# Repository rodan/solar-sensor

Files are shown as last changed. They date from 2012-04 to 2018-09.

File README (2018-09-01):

  Solar sensor device that implements the following:

   - read temperature, humidity, pressure and geiger counter sensors
   - read thermocouple temperature
   - read and set alarms in the real time clock
   - log sensor data on a microSD card
   - control room heating or cooling via RF power switches
   - use a communication protocol to send data to a PC

  there are 4 components in this repository:
  firmware_arduino  - contains the Arduino source code (avr version)
  firmware_avr      - stand-alone source code (avr version)
  hardware_avr      - open source hardware for the main board (avr version)
  server            - server-side implementation of the comm protocol

  pictures of rev02 and rev03 are available at 
            https://picasaweb.google.com/petre.rodan/SolarSensor

  Library dependencies for firmware_arduino software:

  ds3231      https://github.com/rodan/ds3231
  max6675     https://github.com/rodan/max6675
  bmp085      https://github.com/rodan/bmp085
  sht15       http://www.arduino.cc/playground/Code/Sensirion
  IRremote    https://github.com/shirriff/Arduino-IRremote
  SDfatlib    http://code.google.com/p/sdfatlib/

  dependencies for the server-side software:

  linux with working ftdi kernel driver
  sqlite      http://www.sqlite.org/
  gnuplot     http://www.gnuplot.info/

  Hardware needed:

  SHT15 Humidity and Temperature Sensor  - sparkfun sku: SEN-08257
  Grove - Geiger Counter - seeed studio sku: SEN63024P
  3W Solar Panel  - seeed studio sku: POW92136O
  Lithium Ion polymer Battery - 2Ah 3.7V  - seeed studio sku: POW103C1P
  XBee 2mW Chip Antenna - Series 2 ZigBee (2 pcs)  - sparkfun sku: WRL-10415
  XBee Explorer USB  - sparkfun sku: WRL-08687
  main board that includes the LiPo charger, DS3231 to wake up the system, 
    5v boost, one logic level converter, 3.3v stabilized sources, atmega328p uC, 
    uSD card socket, xbee socket, digital cold junction compensated K-type 
    thermocouple IC and mosfets to power off unused modules.

  How does it work

    Power: the main power is from a 2Ah LiPo cell that is charged from the solar panel. a stabilization circuit and a boost give out 3.3V and 5V respectively. a small coin cell battery keeps the DS3231 RTC chip working at all times. the RTC's alarm function is waking up the microcontroller once every 30 minutes.

    Sensors: some are internal and some kept outside. The outside temperature and humidity are measured by a SHT15 chip. the Geiger-Muller tube is also kept outside. the internal temperature is read from the RTC chip, or via a K-type thermocouple.

    Sensor data: is saved to a uSD card and if the receiving PC is up and if the wireless signal haven't got too much interference than a protocol is used to send new data to the PC. it ends up here: http://www.simplex.ro/ro/statie_meteo.html

    Commands: are being given either via the wireless serial interface or via a universal remote control that can speak RC5 (most remotes can).

  Author:          Petre Rodan <2b4eda@subdimension.ro>
  Available from:  https://github.com/rodan/solar-sensor
  License:         GNU GPLv3

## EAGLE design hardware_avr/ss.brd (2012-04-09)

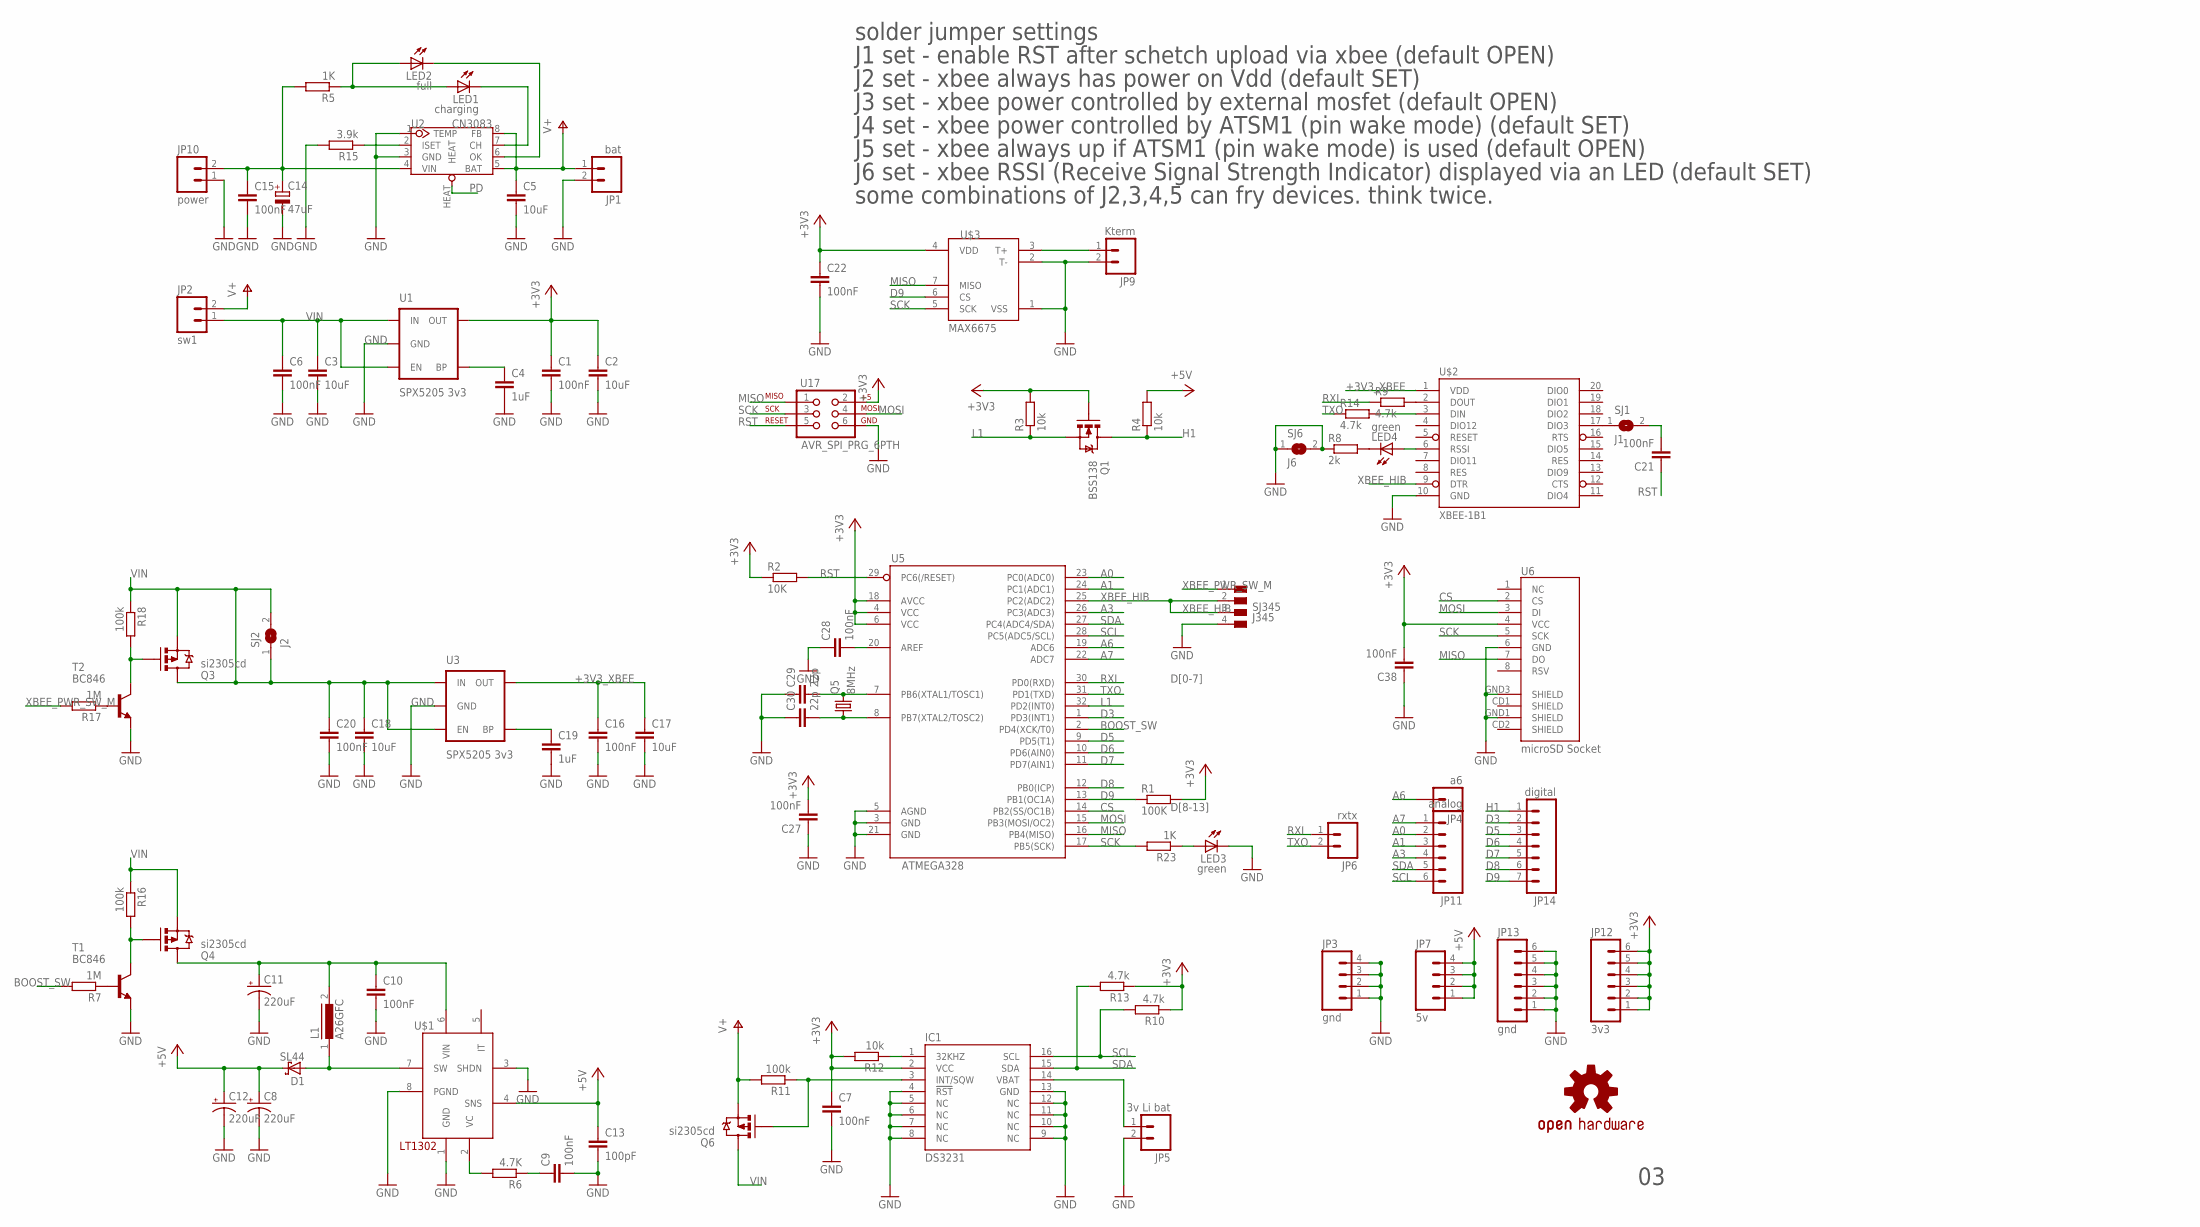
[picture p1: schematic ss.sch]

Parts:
C1, C6, C7, C9, C10, C15, C16, C20, C21, C22, C27, C28, C38: 100nF; C0805
C2, C3, C5, C17, C18: 10uF; C1206
C4, C19: 1uF; C0805
C8, C11, C12: 220uF; PANASONIC_D
C13: 100pF; C0805
C14: 47uF; CT7343
C29, C30: 22p; C0805
D1: SL44; SMC
IC1: DS3231; SO-16
JP1: bat; 1X02
JP2: sw1; 1X02
JP3: gnd; 1X04
JP4: a6; 1X01
JP5: 3v Li bat; 1X02
JP6: rxtx; 1X02
JP7: 5v; 1X04
JP9: Kterm; 1X02
JP10: power; 1X02
JP11: analog; 1X06
JP12: 3v3; 1X06
JP13: gnd; 1X06
JP14: digital; 1X07
L1: A26GFC
LED1: charging; CHIP-LED0805
LED2: full; CHIP-LED0805
LED3, LED4: green; CHIP-LED0805
Q1: BSS138; SOT23-3
Q3, Q4, Q6: si2305cd; SOT23-3_POWER
Q5: 8MHz; CRYSTAL_5X3.2
R1: 100K; R0805W
R2: 10K; R0805W
R3, R4, R12: 10k; R0805W
R5, R23: 1K; R0805W
R6: 4.7K; R0805W
R7, R17: 1M; R0805W
R8: 2k; R0805W
R9, R10, R13, R14: 4.7k; R0805W
R11, R16, R18: 100k; R0805W
R15: 3.9k; R0805W
SJ1: J1; SJ
SJ2: J2; SJ
SJ6: J6; SJ
SJ345: J345; SJ_4P
T1, T2: BC846; SOT23
U1, U3: SPX5205 3v3; SOT23-5
U2: CN3083; SOP8-W/-HEAT
U5: ATMEGA328; TQFP32-08
U6: microSD Socket; MICRO-SD-SOCKET-PP
U17: AVR_SPI_PRG_6PTH; 2X3
U$1: LT1302SOIC8; SO08
U$2: XBEE-1B1; XBEE-1
U$3: MAX6675; SO08-MAX6675
U$7: OSHW-LOGOM; OSHW-LOGO-M

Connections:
+3V3: C1.1, C2.1, C7.1, C22.1, C27.2, C38.2, IC1.2 (VCC), JP12.1, JP12.2, JP12.3, JP12.4, JP12.5, JP12.6, Q1.1 (G), R1.2, R2.1, R3.2, R10.1, R12.2, R13.1, U1.5 (OUT), U5.4 (VCC), U5.6 (VCC), U5.18 (AVCC), U6.4 (VCC), U17.2, U$3.4 (VDD)
+3V3_XBEE: C16.1, C17.1, U3.5 (OUT), U$2.1 (VDD)
+5V: C8.+, C12.+, C13.1, D1.C, JP7.1, JP7.2, JP7.3, JP7.4, R4.2, U$1.4 (SNS)
A0: JP11.2, U5.23 (PC0(ADC0))
A1: JP11.3, U5.24 (PC1(ADC1))
A3: JP11.4, U5.26 (PC3(ADC3))
A6: JP4.1, U5.19 (ADC6)
A7: JP11.1, U5.22 (ADC7)
BOOST_IN: C10.1, C11.+, L1.2, Q4.3 (D), U$1.6 (VIN)
BOOST_SW: R7.2, U5.2 (PD4(XCK/T0))
CS: U5.14 (PB2(SS/OC1B)), U6.2 (CS)
D3: JP14.2, U5.1 (PD3(INT1))
D5: JP14.3, U5.9 (PD5(T1))
D6: JP14.4, U5.10 (PD6(AIN0))
D7: JP14.5, U5.11 (PD7(AIN1))
D8: JP14.6, U5.12 (PB0(ICP))
D9: JP14.7, R1.1, U5.13 (PB1(OC1A)), U$3.6 (CS)
GND: C1.2, C2.2, C3.2, C4.2, C5.2, C6.2, C7.2, C8.-, C9.2, C10.2, C11.-, C12.-, C13.2, C14.-, C15.2, C16.2, C17.2, C18.2, C19.2, C20.2, C22.2, C27.1, C28.1, C29.1, C30.1, C38.1, IC1.4 (!RST), IC1.5 (NC), IC1.6 (NC), IC1.7 (NC), IC1.8 (NC), IC1.9 (NC), IC1.10 (NC), IC1.11 (NC), IC1.12 (NC), IC1.13 (GND), JP1.2, JP3.1, JP3.2, JP3.3, JP3.4, JP5.2, JP9.2, JP10.1, JP13.1, JP13.2, JP13.3, JP13.4, JP13.5, JP13.6, LED3.C, R8.1, R15.2, SJ6.1, SJ6.2, SJ345.4, T1.2 (E), T2.2 (E), U1.2 (GND), U2.1 (TEMP), U2.3 (GND), U3.2 (GND), U5.3 (GND), U5.5 (AGND), U5.21 (GND), U6.6 (GND), U6.GND1 (SHIELD), U6.GND3 (SHIELD), U17.6, U$1.1 (GND), U$1.3 (SHDN), U$1.8 (PGND), U$2.10 (GND), U$3.1 (VSS), U$3.2 (T-)
H1: JP14.1, Q1.3 (D), R4.1
L1: Q1.2 (S), R3.1, U5.32 (PD2(INT0))
MISO: U5.16 (PB4(MISO)), U6.7 (DO), U17.1, U$3.7 (MISO)
MOSI: U5.15 (PB3(MOSI/OC2)), U6.3 (DI), U17.4
unnamed: IC1.3 (INT/SQW), Q6.1 (G), R11.1
unnamed: C4.1, U1.4 (BP)
unnamed: D1.A, L1.1, U$1.7 (SW)
unnamed: SJ1.1, U$2.17 (DIO3)
unnamed: C19.1, U3.4 (BP)
unnamed: LED4.C, R8.2
unnamed: LED4.A, U$2.6 (RSSI)
unnamed: IC1.1 (32KHZ), R12.1
unnamed: R15.1, U2.2 (ISET)
unnamed: IC1.14 (VBAT), JP5.1
unnamed: R6.2, U$1.2 (VC)
unnamed: C14.+, C15.1, JP10.2, R5.2, U2.4 (VIN)
unnamed: C9.1, R6.1
unnamed: LED1.A, LED2.A, R5.1
unnamed: LED1.C, U2.7 (CH)
unnamed: LED2.C, U2.6 (OK)
unnamed: C21.2, SJ1.2
unnamed: R17.1, T2.1 (B)
unnamed: C30.2, Q5.P$1 (1), U5.8 (PB7(XTAL2/TOSC2))
unnamed: Q3.1 (G), R18.2, T2.3 (C)
unnamed: C29.2, Q5.P$2 (2), U5.7 (PB6(XTAL1/TOSC1))
unnamed: C28.2, U5.20 (AREF)
unnamed: R9.2, U$2.2 (DOUT)
unnamed: R14.2, U$2.3 (DIN)
unnamed: R7.1, T1.1 (B)
unnamed: Q4.1 (G), R16.2, T1.3 (C)
unnamed: LED3.A, R23.1
PD: U2.HEAT
RST: C21.1, R2.2, U5.29 (PC6(/RESET)), U17.5
RXI: JP6.1, R9.1, U5.30 (PD0(RXD))
SCK: R23.2, U5.17 (PB5(SCK)), U6.5 (SCK), U17.3, U$3.5 (SCK)
SCL: IC1.16 (SCL), JP11.6, R10.2, U5.28 (PC5(ADC5/SCL))
SDA: IC1.15 (SDA), JP11.5, R13.2, U5.27 (PC4(ADC4/SDA))
T+: JP9.1, U$3.3 (T+)
TXO: JP6.2, R14.1, U5.31 (PD1(TXD))
V+: C5.1, JP1.1, JP2.2, Q6.2 (S), R11.2, U2.5 (BAT), U2.8 (FB)
VIN: C3.1, C6.1, C18.1, C20.1, JP2.1, Q3.2 (S), Q3.3 (D), Q4.2 (S), Q6.3 (D), R16.1, R18.1, SJ2.1, SJ2.2, U1.1 (IN), U1.3 (EN), U3.1 (IN), U3.3 (EN)
XBEE_HIB: SJ345.2, SJ345.3, U5.25 (PC2(ADC2)), U$2.9 (DTR)
XBEE_PWR_SW_M: R17.2, SJ345.1

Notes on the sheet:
D[0-7]
D[8-13]
J1 set - enable RST after schetch upload via xbee (default OPEN)
J2 set - xbee always has power on Vdd (default SET)
solder jumper settings
J3 set - xbee power controlled by external mosfet (default OPEN)
J4 set - xbee power controlled by ATSM1 (pin wake mode) (default SET)
J5 set - xbee always up if ATSM1 (pin wake mode) is used (default OPEN)
J6 set - xbee RSSI (Receive Signal Strength Indicator) displayed via an LED (default SET)
some combinations of J2,3,4,5 can fry devices. think twice.

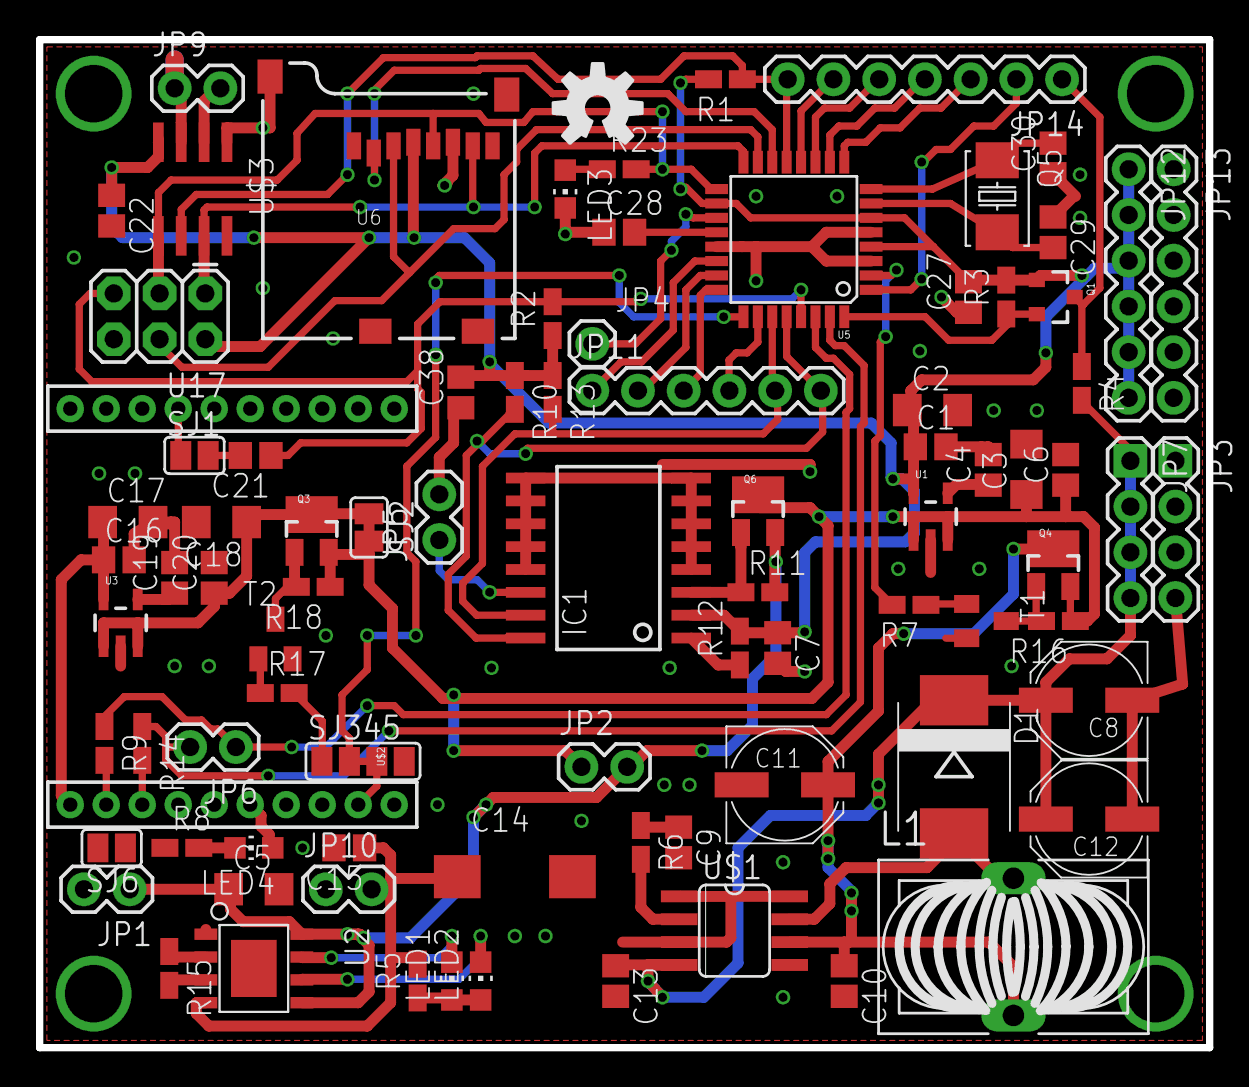
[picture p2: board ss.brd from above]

Board: 2 copper layers, 65.0 x 56.0 mm, 87 parts (0 on the bottom side), 60 nets.

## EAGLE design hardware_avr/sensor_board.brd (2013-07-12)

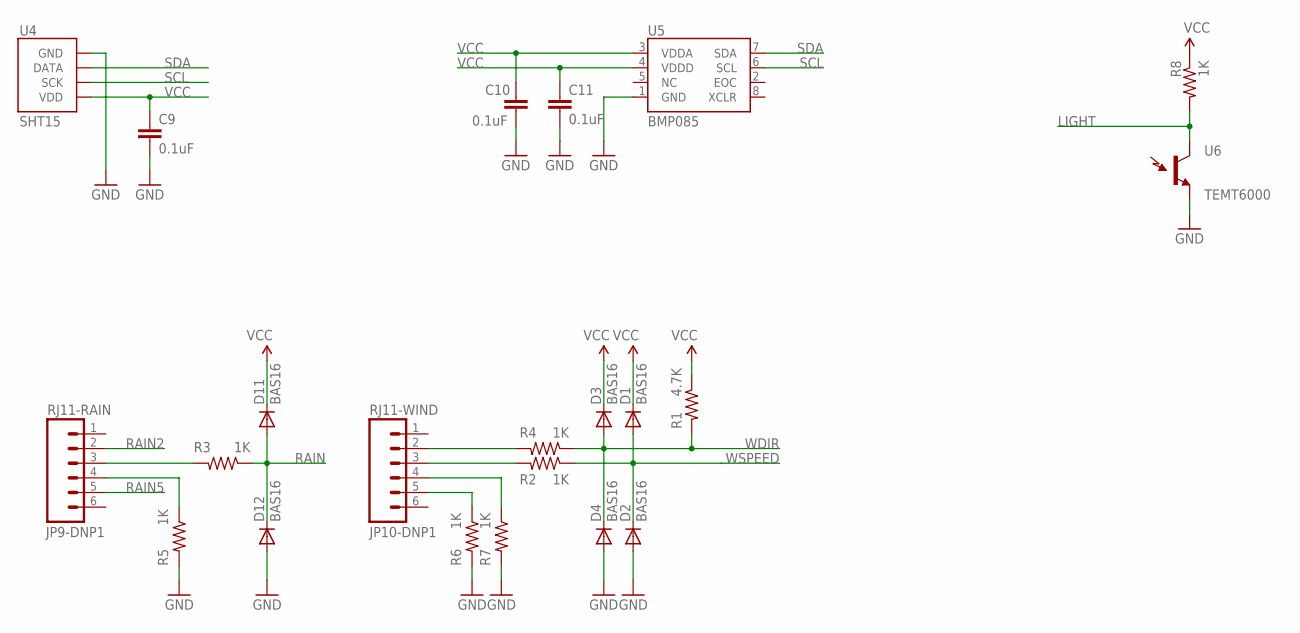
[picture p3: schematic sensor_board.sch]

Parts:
C9, C10, C11: 0.1uF; 0402-CAP
D1, D2, D3, D4, D11, D12: BAS16; SOD-323
JP9-DNP1: RJ11-RAIN; RJ11-6
JP10-DNP1: RJ11-WIND; RJ11-6
R1: 4.7K; 0402-RES
R2, R3, R4, R5, R6, R7, R8: 1K; 0402-RES
U4: SHT15; SHT1X
U5: BMP085
U6: TEMT6000; TEMT6000-SEN

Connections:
GND: C9.2, C10.1, C11.2, D2.2 (A), D4.2 (A), D12.2 (A), R5.2, R6.2, R7.2, U4.1 (GND), U5.1 (GND), U6.EMITTER (E1)
LIGHT: R8.2, U6.COLLECTOR (C1)
unnamed: JP10-DNP1.2, R4.2
unnamed: JP10-DNP1.3, R2.2
unnamed: JP9-DNP1.3, R3.2
unnamed: JP9-DNP1.4, R5.1
unnamed: JP10-DNP1.5, R6.1
unnamed: JP10-DNP1.4, R7.1
RAIN: D11.2 (A), D12.1 (C), R3.1
RAIN2: JP9-DNP1.2
RAIN5: JP9-DNP1.5
SCL: U4.3 (SCK), U5.6 (SCL)
SDA: U4.2 (DATA), U5.7 (SDA)
VCC: C9.1, C10.2, C11.1, D1.1 (C), D3.1 (C), D11.1 (C), R1.1, R8.1, U4.4 (VDD), U5.3 (VDDA), U5.4 (VDDD)
WDIR: D3.2 (A), D4.1 (C), R1.2, R4.1
WSPEED: D1.2 (A), D2.1 (C), R2.1

Board: 2 copper layers, 22 parts (0 on the bottom side), 14 nets, no tracks yet.

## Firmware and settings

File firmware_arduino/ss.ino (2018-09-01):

/*

  Solar sensor program that implements the following:

   - read temperature, humidity and geiger counter sensors
   - read and set alarms in the real time clock
   - log sensor data on an microSD card
   - use a communication protocol to send data to a server
   - control room heating or cooling via RF power switches (based on internal temperatures)

  see the README file for more info.

  Author:          Petre Rodan <2b4eda@subdimension.ro>
  Revision:        03
  Available from:  https://github.com/rodan/solar-sensor
  License:         GNU GPLv3

  GNU GPLv3 license:
  
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
*/

#include "config.h"

#ifdef IR_REMOTE
#include <IRremote.h>
#include <IRremoteInt.h>
#endif

#ifdef SHT15
#include <Sensirion.h>
#endif

#ifdef MAX6675
#include <max6675.h>
#endif

#ifdef BMP085
#include <bmp085.h>
#endif

#ifdef INTERTECHNO
#include <intertechno.h>
#endif

#include <Wire.h>
#include <ds3231.h>
#include <SPI.h>

#ifdef SDFAT
#include <SdFat.h>
#include <SdFatUtil.h>
#endif

#include "ss.h"

#define SENSOR_ID 1

// XBEE_ACTIVE_LOW must be 1 with the following jumper settings:
//   J2 set, J3 open, J4 set, J5 open 
//            (xbee always receives power, hibernating if ATSM1 set - this is the default state)
//   J2 set, J3 open, J4 open, J5 set 
//            (xbee always receives power, always active if ATSM1 set) 
//
// XBEE_ACTIVE_LOW must be 0 with the following jumper settings:
//   J2 open, J3 set, J4 open, J5 set
//            (xbee receives power only when pin_xbee_ctrl is HIGH)
//
#define XBEE_ACTIVE_LOW "1"

// arduino digital pins
#define pin_counter 2
#define pin_ir 3
#define pin_boost_sw 4
#define pin_rf 5
#define pin_SHT_SCK 8
#define pin_cs_kterm 9

// analog pins
#define pin_xbee_ctrl A2
#define pin_light A3
#define pin_SHT_DATA A4
//SDA   A4
//SCL   A5

// OP_AUTOMATIC - when the device is woken up by the RTC
// OP_MANUAL - when the device is woken up by a human
#define OP_MANUAL 0
#define OP_AUTOMATIC 1
unsigned char op_mode = OP_AUTOMATIC;

// how many minutes to sleep between automatic measurements
// must be an integer between 5 and 59

#ifdef DATALOGGER
unsigned char sleep_period = 1;
#else
unsigned char sleep_period = 30;
#endif

unsigned long stage_prev = 0;
boolean stage_started[7] = { false, false, false, false, false, false, false };

byte stage_num = 0;

// refresh in OP_MANUAL mode
unsigned long refresh_prev = 0;

// not much space for misc buffers
#define BUFF_MAX 64

float ext_temp = 0.0;
float ext_hum = 0.0;
float ext_dew = 0.0;
uint32_t ext_pressure = 0;
uint8_t ext_light = 0;

// Ktherm
float kth_temp = 0.0;

#ifdef BMP085
// bmp085 pressure sensor
struct bmp085 b;
#endif

#ifdef INTERTECHNO
// intertechno rf switch
struct it its;
#endif

// rtc
struct ts t;
float int_temp;

// serial console
char recv[BUFF_MAX];
uint8_t recv_size = 0;

unsigned long shtd_prev = 0;

#ifdef SDFAT
#define BUFF_LOG 64
// uSD
SdFat sd;
SdFile f;
#endif

#ifdef IR_REMOTE
// infrared remote
IRrecv irrecv(pin_ir);
unsigned long result_last = 4294967295UL;       // -1
unsigned int ir_delay = 300;    // delay between repeated button presses
unsigned long ir_delay_prev = 0;
#endif

// counter
boolean counter_state = HIGH;
boolean counter_state_last = HIGH;
volatile unsigned long counter_c = 0;   //counts
unsigned long counter_c_last = 0;       //counts at start of counter_interval
unsigned long counter_cpm;      //counts per interval
//unsigned long counter_interval = 60000;
unsigned long counter_prev = 0;

#define BUFF_OUT 80
char output[BUFF_OUT];

void setup()
{
    pinMode(pin_counter, INPUT);
    pinMode(pin_xbee_ctrl, OUTPUT);
    pinMode(pin_boost_sw, OUTPUT);

    xbee_off();
    Wire.begin();
    TWBR = 0xFF;                // slow down hardware i2c clock
    // since we use longer than recommended wires

    // verify if Alarm2 woked us up  ( status register XXXX XX1X )
    if ((DS3231_get_sreg() & 0x02) == 0) {
        // powered up by manual switch, not by alarm
        op_mode = OP_MANUAL;
        //stage4();
    }
        
    setup_a2();
    
    // this will pull up D9 - needed for later SPI
#ifdef MAX6675
    tk_init(pin_cs_kterm);
#else
    pinMode(pin_cs_kterm, OUTPUT);
    digitalWrite(pin_cs_kterm, HIGH);
#endif

#ifdef SDFAT
    if (!sd.init(SPI_HALF_SPEED))
        sd.initErrorHalt();
#endif

    DS3231_init(0x06);
    Serial.begin(9600);

#ifdef BMP085
    bmp085_init(&b);
#endif

#ifdef INTERTECHNO
    its.pin = pin_rf;
#if defined(F_CPU) && F_CPU == 8000000
    its.rf_cal_on = -7;
    its.rf_cal_off = -7;
#elif defined(F_CPU) && F_CPU == 16000000
    its.rf_cal_on = -1;
    its.rf_cal_off = -1;
#else
    // mkaaaaay
    its.rf_cal_on = -1;
    its.rf_cal_off = -1;
#endif
    pinMode(its.pin, OUTPUT);
    digitalWrite(its.pin, LOW);

#endif

#ifdef IR_REMOTE
    irrecv.enableIRIn();
#endif
    //Serial.print("ram ");
    //Serial.println(FreeRam());
    //Serial.println("?");
}

void loop()
{

    // initial wait, warmup, counter, hum, post wait, sleep
    //unsigned long stage_timing[7] = { 2000, 4000, 60000, 1000, 20000, 5000, (sleep_period * 60000) - 108000 };
#ifdef DATALOGGER
    unsigned long stage_timing[7] = { 2000, 4000, 1, 1000, 20000, 5000, (sleep_period * 60000) - 108000 };
#else
    unsigned long stage_timing[7] = { 2000, 4000, 60000, 1000, 20000, 60000, (sleep_period * 60000) - 108000 };
#endif

    unsigned long now = millis();

#ifdef IR_REMOTE
    ir_decode();
#endif

    console_decode();

    if (op_mode == OP_AUTOMATIC) {
        switch (stage_num) {
        case 0:
            if (!stage_started[1] && (now - stage_prev > stage_timing[0])) {
                stage_prev = now;
                stage_started[0] = false;
                stage_started[1] = true;
                stage1();
            }
            break;
        case 1:
            if (!stage_started[2] && (now - stage_prev > stage_timing[1])) {
                stage_prev = now;
                stage_started[1] = false;
                stage_started[2] = true;
                stage2();
            }
            break;
        case 2:
            read_counter();
            if (!stage_started[3] && (now - stage_prev > stage_timing[2])) {
                stage_prev = now;
                stage_started[2] = false;
                stage_started[3] = true;
                stage3();
            }
            break;
        case 3:
            if (!stage_started[4] && (now - stage_prev > stage_timing[3])) {
                stage_prev = now;
                stage_started[3] = false;
                stage_started[4] = true;
                stage4();
            }
            break;
        case 4:
            if (!stage_started[5] && (now - stage_prev > stage_timing[4])) {
                stage_prev = now;
                stage_started[4] = false;
                stage_started[5] = true;
                stage5();
            }
            break;
        case 5:
            if (!stage_started[6]
                && ((now - stage_prev > stage_timing[5])
                    || (now - shtd_prev > 20000))) {
                // if there is more than 20s of inactivity, shutdown
                stage_prev = now;
                stage_started[5] = false;
                stage_started[6] = true;
                stage6();
            }
        case 6:
            if (!stage_started[0] && (now - stage_prev > stage_timing[6])) {
                stage_prev = now;
                stage_started[6] = false;
                stage_started[0] = true;
                stage_num = 0;
            }
            break;

        }                       // switch
    } else {                    // manual operation

        read_counter();

        if ((now - counter_prev > 60000)) {
            counter_cpm = counter_c - counter_c_last;
            counter_c_last = counter_c;
            counter_prev = now;
        }
        // once a while (10s) refresh stuff
        if ((now - refresh_prev > 10000)) {
            refresh_prev = now;

            // if the RTC woke up the device in the meantime
            if ((DS3231_get_sreg() & 0x02) == 2) {
                // clear all alarms and thus disable RTC poweron
                DS3231_set_sreg(0x00);
                setup_a2();
            }
        }
    }

}

#ifdef DEBUG
void log_debug(const char *s)
{
    Serial.print("DBG ");
    Serial.print(millis());
    Serial.print(" ");
    Serial.println(s);
}
#endif

// IR
#ifdef IR_REMOTE
void ir_decode()
{
    decode_results results;
    unsigned long now = millis();

    //int ir_number = -1;

    if (irrecv.decode(&results)) {

        if (results.value >= 2048)
            results.value -= 2048;

        if (result_last == results.value && now - ir_delay_prev < ir_delay) {
            results.value = 11111;
        }

        switch (results.value) {
/*      // RC5 codes
        case 1: // 1
            ir_number = 1;
            break;
        case 2: // 2
            ir_number = 2;
            break;
        case 3: // 3
            ir_number = 3;
            break;
        case 4: // 4
            ir_number = 4;
            break;
        case 5: // 5
            ir_number = 5;
            break;
        case 6: // 6
            ir_number = 6;
            break;
        case 7: // 7
            ir_number = 7;
            break;
        case 8: // 8
            ir_number = 8;
            break;
        case 9: // 9
            ir_number = 9;
            break;
        case 0: // 0
            ir_number = 0;
            break;
        case 10: // 10
            ir_number = 10;
            break;
*/
        case 56:               // AV
            Serial.println("");
            Serial.print("EHLO s");
            Serial.println(SENSOR_ID);
            break;
/*
        case 36: // red
          break;
        case 35: // green
          break;
        case 14: // yellow
          break; */
        case 12:               // power
            op_mode = OP_MANUAL;
            if ((DS3231_get_sreg() & 0x02) == 2) {
                // clear all alarms and thus disable RTC poweron
                DS3231_set_sreg(0x00);
            }
            break;
/*        case 50: // zoom
            break;
        case 39: // sub
            break;
        case 44: // slow
            break;
        case 60: // repeat
            break;
        case 15: // disp
            break;
        case 38: // sleep
            break;
        case 32: // up
            break;
        case 33: // down
            break;
        case 16: // right
            break;
        case 17: // left
            break;
        case 59: // ok
            break;
        case 34: // back
            break;
        case 19: // exit
            break;
        case 18: // menu
            break;
        case 13: // mute
            break;
        case 16: // vol+
            break;
        case 17: // vol-
            break;
        case 28: // ch+
            rf_tx_cmd(its, 0xb6, INTERTECHNO_CMD_ON);
            break;
        case 29: // ch-
            rf_tx_cmd(its, 0xb6, INTERTECHNO_CMD_OFF);
            break;
*/
        case 36:               // record
            Serial.println("GET time");
            break;
        case 54:               // stop
            xbee_off();
            boost_off();
            break;
        case 14:               // play
            xbee_on();
            boost_on();
            break;
/*        case 31: // pause
            break;
*/
        case 35:               // rew
            stage4();
            break;
/*        case : // fwd
            break;
*/
        }                       // case

        if (results.value != 11111) {
            result_last = results.value;
            ir_delay_prev = now;
        }
        irrecv.resume();        // Receive the next keypress
    }

}
#endif

//   sensors

int measure_ext()
{

#ifdef SHT15
    uint16_t sht_raw;
    Sensirion sht = Sensirion(pin_SHT_DATA, pin_SHT_SCK);

    // disable hardware i2c
    TWCR &= ~(1 << 2);
    pinMode(pin_SHT_SCK, OUTPUT);

    sht.meas(TEMP, &sht_raw, BLOCK);
    ext_temp = sht.calcTemp(sht_raw);
    if (ext_temp == -40.1) {
        ext_temp = 0;
        return 1;
    }
    sht.meas(HUMI, &sht_raw, BLOCK);
    ext_hum = sht.calcHumi(sht_raw, ext_temp);
    ext_dew = sht.calcDewpoint(ext_hum, ext_temp);

    TWCR |= (1 << 2);           // enable hardware i2c
    //Wire.begin();
    //TWBR = 0xFF;
#else
    ext_hum = 0;
    ext_temp = 0;
    ext_dew = 0;
#endif

#ifdef BMP085
    b.oss = 3;
    bmp085_read_sensors(&b);
    ext_pressure = b.ppa;
#endif

    ext_light = analogRead(pin_light) / 4;

    return 0;
}

void measure_int()
{
    int_temp = DS3231_get_treg();
#ifdef MAX6675
    kth_temp = 0.25 * tk_get_raw(pin_cs_kterm);
#endif
}

void read_counter()
{
    counter_state = digitalRead(pin_counter);
    if (counter_state != counter_state_last) {
        if (counter_state == LOW) {
            counter_c++;
        }
        counter_state_last = counter_state;
    }
}

void stage1()
{
    stage_num = 1;

#ifdef DEBUG
    const char msg[] = "s1";
    log_debug(msg);
#endif

    boost_on();
}

void stage2()
{
    stage_num = 2;

#ifdef DEBUG
    const char msg[] = "s2";
    log_debug(msg);
#endif

    counter_c_last = counter_c;
}

void stage3()
{
    stage_num = 3;

#ifdef DEBUG
    const char msg[] = "s3";
    log_debug(msg);
#endif

//  counter_cpm = ( counter_c - counter_c_last ) * 60000.0 / counter_interval;
    counter_cpm = counter_c - counter_c_last;
    boost_off();
    xbee_on();
}

void stage4()
{
    char tmp1[7], tmp2[7], tmp3[7], tmp4[7], tmp5[9];
    stage_num = 4;

#ifdef DEBUG
    const char msg[] = "s4";
    log_debug(msg);
#endif

    measure_ext();
    measure_int();

    DS3231_get(&t);

    // floats cannot be used as %f in *printf()
    dtostrf(ext_temp, 2, 2, tmp1);
    dtostrf(ext_hum, 2, 2, tmp2);
    dtostrf(ext_dew, 2, 2, tmp3);
    dtostrf(int_temp, 2, 2, tmp4);
    dtostrf(kth_temp, 2, 2, tmp5);

    snprintf(output, BUFF_OUT,
             "s%d %d-%02d-%02dT%02d:%02d:%02d %s %s %s %ld %d %ld %s %s\r\n",
             SENSOR_ID, t.year, t.mon, t.mday, t.hour, t.min, t.sec, tmp1, tmp2,
             tmp3, ext_pressure, ext_light, counter_cpm, tmp4, tmp5);

    if (op_mode == OP_AUTOMATIC) {
#ifdef SDFAT
        char f_name[9];
        snprintf(f_name, 9, "%d%02d%02d", t.year, t.mon, t.mday);
        f.open(f_name, O_RDWR | O_CREAT | O_AT_END);
        f.write(output, strlen(output));
        //if (f.write(output, strlen(output)) != strlen(output)) {
        //error("write failed");
        //}
        f.close();
#endif
    } else {
        Serial.println(output);
    }
}

void stage5()
{
    // try to talk with the server
    stage_num = 5;

#ifdef DEBUG
    const char msg[] = "s5";
    log_debug(msg);
#endif

#ifdef IR_REMOTE
    // zero out the Timer Interrupt Mask Register TIMSK IRremote is using
    // this will enable much more precise transmission but disable IR commands
    TIMER_DISABLE_INTR;
#endif

    Serial.println("");
    Serial.print("EHLO s");
    Serial.println(SENSOR_ID);
    shtd_prev = millis();
}

void stage6()
{
    stage_num = 6;

#ifdef DEBUG
    const char msg[] = "s6";
    log_debug(msg);
#endif

#ifdef INTERTECHNO
    // home automation
    // use the radio switches to start/stop the fan or the heater

    // june/july/august heat
    if ((t.mon > 5) && (t.mon < 9)) {
        if ((int_temp > 27) && (ext_temp < 24)) {
            // start the fan/AC/chiller
            rf_tx_cmd(its, 0xb7, INTERTECHNO_CMD_ON);
        } else {
            // stop the fan/AC/chiller
            rf_tx_cmd(its, 0xb7, INTERTECHNO_CMD_OFF);
        }
    }

    // nov/dec/jan cold
    if ((t.mon > 10) && (t.mon < 2)) {
        if ((int_temp < 19) && (ext_temp < 10)) {
            // start the heater
            rf_tx_cmd(its, 0xb6, INTERTECHNO_CMD_ON);
        } else {
            // stop the heater
            rf_tx_cmd(its, 0xb6, INTERTECHNO_CMD_OFF);
        }
    }
#endif

    xbee_off();

    setup_a2();

    // clear all alarms and thus disable RTC poweron
    DS3231_set_sreg(0x00);
}

// set Alarm2 to wake up the device
void setup_a2()
{
    unsigned char wakeup_min;
    DS3231_get(&t);
#ifdef DATALOGGER
    wakeup_min = t.min + sleep_period;
#else
    wakeup_min = (t.min / sleep_period + 1) * sleep_period;
#endif

    if (wakeup_min > 59)
        wakeup_min -= 60;

    boolean flags[4] = { 0, 1, 1, 1 };

    // set Alarm2
    DS3231_set_a2(wakeup_min, 0, 0, flags);

    // activate Alarm2
    DS3231_init(0x06);
}

//   console related

void console_decode()
{
    char in;
    //char buff[BUFF_MAX];

    if (Serial.available() > 0) {
        in = Serial.read();

        //Serial.println(in);

        if ((in == 10 || in == 13) && (recv_size > 0)) {
            parse_cmd(recv, recv_size);
            recv_size = 0;
            recv[0] = 0;
        } else if (in < 31 || in > 122) {       // ~[0-9A-Za-z ]
            // ignore 
        } else if (recv_size > BUFF_MAX - 2) {
            // drop
            recv_size = 0;
            recv[0] = 0;
        } else if (recv_size < BUFF_MAX - 2) {
            recv[recv_size] = in;
            recv[recv_size + 1] = 0;
            //snprintf(buff,BUFF_MAX,"partial,%d: %s,%d,%d\n",recv_size,recv,recv[recv_size],in);
            //Serial.println(buff);
            recv_size += 1;
        }
    }                           // Serial.available
}

void parse_cmd(char *cmd, uint8_t cmdsize)
{
    char f_name[9];

#ifdef SDFAT
    int i;
    unsigned int f_size;
    char f_c[BUFF_LOG];
    int rrv = BUFF_LOG;
#endif

/*     
    Serial.print("DBG cmd='");
    Serial.print(cmd[0], DEC);
    Serial.print("' len=");
    Serial.print(cmdsize, DEC);
    Serial.print(" cmd=");
    for (i=0;i<cmdsize;i++) {
        Serial.print(cmd[i]);
    }
    Serial.println("");
*/

    if (cmd[0] == 71 && cmdsize < 13 && cmdsize > 4) {
        // GET 20111020
        // this cmd will read that file from the uSD

        if (stage_num == 5)
            shtd_prev = millis();

        strncpy(f_name, &cmd[4], 9);
        if (strncmp(f_name, "NOW", 3) == 0) {
            Serial.println(output);
            console_send_ok();
        } else {
#ifdef SDFAT
            f.open(f_name, O_READ);
            f_size = f.fileSize();
            Serial.print("LEN ");
            Serial.print(f_name);
            Serial.print(" ");
            Serial.println(f_size);

            if (f_size > 0) {
                while (rrv == BUFF_LOG) {
                    rrv = f.read(&f_c[0], BUFF_LOG);
                    for (i = 0; i < rrv; i++) {
                        Serial.print(f_c[i]);
                    }
                    // xbees start loosing data after the first 2k if no delay is given
                    delay(100);
                }
                console_send_ok();
            } else {
                console_send_err();
            }

            f.close();
#else
            console_send_err();
#endif
        }
    } else if (cmd[0] == 72) {
        if (strncmp(cmd, "HALT", 4) == 0) {
            // go' sleep some
            stage_started[5] = false;
            stage_started[6] = true;
            stage6();
        }
    } else if ((cmd[0] == 84) && (cmdsize == 16)) {
        //T355720619112011
        t.sec = inp2toi(cmd, 1);
        t.min = inp2toi(cmd, 3);
        t.hour = inp2toi(cmd, 5);
        t.wday = inp2toi(cmd, 7);
        t.mday = inp2toi(cmd, 8);
        t.mon = inp2toi(cmd, 10);
        t.year = inp2toi(cmd, 12) * 100 + inp2toi(cmd, 14);
        DS3231_set(t);
        console_send_ok();
    } else {
        console_send_err();
    }

}

void console_send_ok()
{
    Serial.println("OK");
}

void console_send_err()
{
    Serial.println("ERR");
}

void boost_on()
{
    digitalWrite(pin_boost_sw, HIGH);
}

void boost_off()
{
    digitalWrite(pin_boost_sw, LOW);
}

void xbee_on()
{
    if (XBEE_ACTIVE_LOW) {
        digitalWrite(pin_xbee_ctrl, LOW);
    } else {
        digitalWrite(pin_xbee_ctrl, HIGH);
    }
}

void xbee_off()
{
    if (XBEE_ACTIVE_LOW) {
        digitalWrite(pin_xbee_ctrl, HIGH);
    } else {
        digitalWrite(pin_xbee_ctrl, LOW);
    }
}

/*
int open_file(char fname[10])
{
    //int wait = 200;
    //char fname[9];

    //DS3231_get(&t);
    //snprintf(fname, 9, "%d%02d%02d", t.year, t.mon, t.mday);

    // open the file for write at end like the Native SD library
    return f.open(fname, O_RDWR | O_CREAT | O_AT_END);
}
*/

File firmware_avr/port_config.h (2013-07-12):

#ifndef __PORT_CONFIG_H__
#define __PORT_CONFIG_H__

#include <avr/io.h>

// i2c
#define I2C_MASTER_DIR  DDRC
#define I2C_MASTER_OUT  PORTC
#define I2C_MASTER_IN   PINC
#define I2C_MASTER_SCL  0x20
#define I2C_MASTER_SDA  0x10

// infrared RC
#define IR_DDR          DDRD
#define IR_PIN          PIND
#define IR              0x8

#endif

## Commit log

2011-12-07 initial import
    [calc.ods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]
2011-12-12 if GET NOW worked ok all day long, don't read the current day from the card
2011-12-17 use hibernation pin on the ZigBee
2012-01-10 arduino 1.0 compatibility
2012-02-14 switch to rev03
2012-02-14 removed cruft
    [calc.ods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]
2012-02-15 here comes the xml
    [ss.brd, ss.sch]
2012-02-15 ss board rev03. draft
    [ss.brd, ss.sch]
2012-03-18 hopefully flawless
    [ss.brd, ss.sch]
2012-03-18 rev03 sent to manufacture
    [ss.brd]
2012-03-25 rev03 related pin reassignments
2012-04-07 d9 needs external weak pullup during programming
    [ss.brd, ss.sch]
2012-04-07 yay, boost switch
2012-04-07 thermocouple t- must be grounded
    [ss.brd, ss.sch]
2012-04-09 move power socket
    [ss.brd, ss.sch]
2012-04-15 add pressure sensor
2012-10-13 add support for intertechno RF switches
2013-07-12 add standalone avr source code
    [sensor_board.brd, sensor_board.sch, ss.brd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]

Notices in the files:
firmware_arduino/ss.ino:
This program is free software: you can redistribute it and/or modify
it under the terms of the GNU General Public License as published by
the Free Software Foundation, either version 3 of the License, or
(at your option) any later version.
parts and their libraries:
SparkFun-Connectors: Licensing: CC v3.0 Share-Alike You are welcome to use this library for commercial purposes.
